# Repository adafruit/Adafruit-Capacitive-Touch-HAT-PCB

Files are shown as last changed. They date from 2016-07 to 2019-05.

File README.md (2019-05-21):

## Adafruit Capacitive Touch HAT PCB
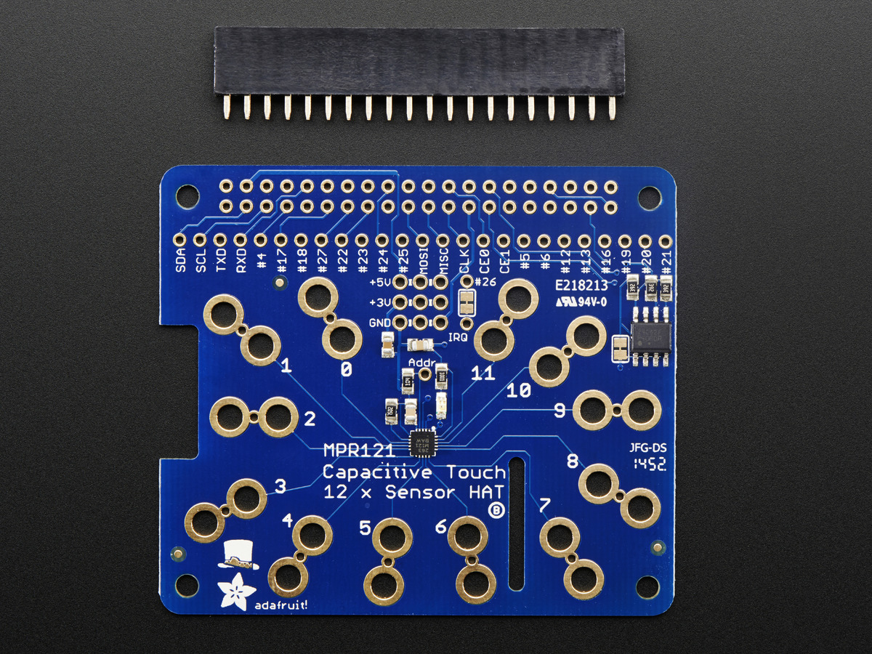
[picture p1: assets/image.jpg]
<a href="http://www.adafruit.com/products/2340"><br/>
Click here to purchase one from the Adafruit shop</a>

This touch-able add on HAT for Raspberry Pi will inspire your next interactive project with 12 capacitive touch sensors. Capacitive touch sensing works by detecting when a person (or animal) has touched one of the sensor electrodes. Capacitive touch sensing used for stuff like touch-reactive tablets and phones, as well as control panels for appliances, which is where you may have used it before. This HAT allows you to create electronics that can react to human touch, with up to 12 individual sensors.

The HAT has 12 'figure 8' holes in it that can be gripped onto with alligator clip cables. Attach one side of the clip to the HAT and the other side to something electrically conductive (like metal) or full of water (like vegetables or fruit!) Then start up our handy Python library code to detect when the object is touched. That's pretty much it, very easy! For advanced users, you can also solder to a pad to make a slimmer & more permanent connection.

PCB files for the Adafruit Capacitive Touch HAT. The format is EagleCAD schematic and board layout
- https://www.adafruit.com/products/2340

### License

Adafruit invests time and resources providing this open source design, please support Adafruit and open-source hardware by purchasing products from [Adafruit](https://www.adafruit.com)!

All text above must be included in any redistribution

Designed by Limor Fried/Ladyada for Adafruit Industries.
Creative Commons Attribution/Share-Alike, all text above must be included in any redistribution. 
See license.txt for additional information.

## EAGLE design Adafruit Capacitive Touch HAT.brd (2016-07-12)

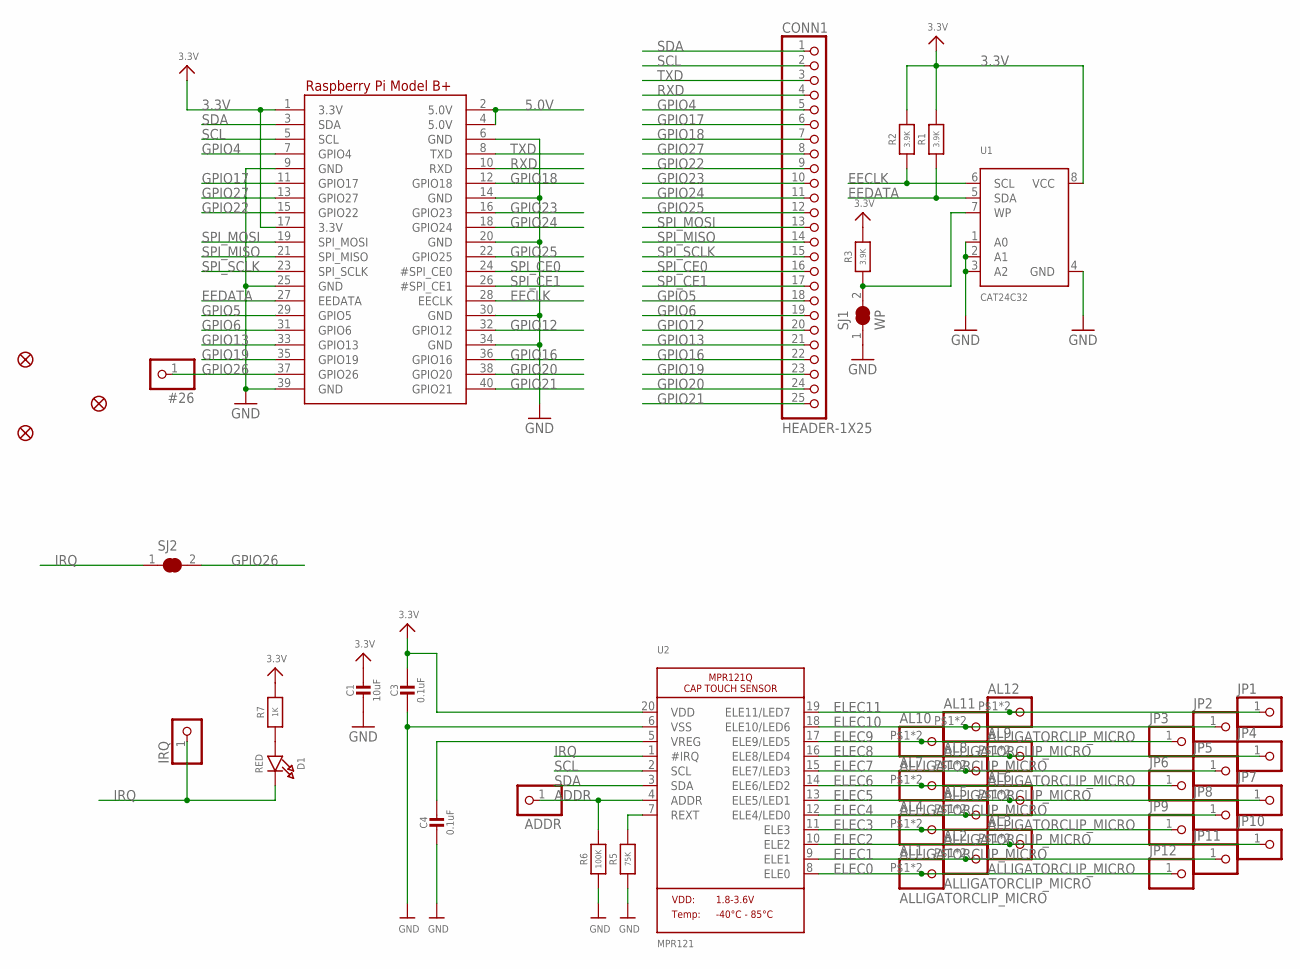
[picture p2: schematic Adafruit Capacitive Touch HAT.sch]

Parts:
#26: HEADER-1X1ROUND; 1X01_ROUND
ADDR: HEADER-1X1ROUND; 1X01_ROUND
AL1, AL2, AL3, AL4, AL5, AL6, AL7, AL8, AL9, AL10, AL11, AL12: ALLIGATORCLIP_MICRO; ALLIGATORCLIP
C1: 10uF; 0805-NO
C3, C4: 0.1uF; 0805-NO
CONN1: HEADER-1X25; 1X25_ROUND_70MIL
D1: RED; CHIPLED_0805_NOOUTLINE
FID1, FID2, FID3: FIDUCIAL""; FIDUCIAL_1MM
IRQ: HEADER-1X1ROUND; 1X01_ROUND
JP1, JP2, JP3, JP4, JP5, JP6, JP7, JP8, JP9, JP10, JP11, JP12: HEADER-1X1ROUND; 1X01_ROUND
R1, R2, R3: 3.9K; 0805-NO
R5: 75K; 0805-NO
R6: 100K; 0805-NO
R7: 1K; 0805-NO
RPI1: RASPBERRYPI_BPLUS_HATSLOTS; PI_HAT_SLOTS
SJ1: WP; SOLDERJUMPER_CLOSEDWIRE
SJ2: SOLDERJUMPER_CLOSED; SOLDERJUMPER_CLOSEDWIRE
U1: CAT24C32; SOIC8_150MIL
U2: MPR121; QFN20_3MM_NOTHERMAL

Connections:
3.3V: C1.1, C3.1, R1.2, R2.2, R3.2, R7.2, RPI1.1 (3.3V), RPI1.17 (3.3V), U1.8 (VCC), U2.20 (VDD)
5.0V: RPI1.2 (5.0V), RPI1.4 (5.0V)
ADDR: ADDR.1, R6.2, U2.4 (ADDR)
EECLK: R2.1, RPI1.28 (EECLK), U1.6 (SCL)
EEDATA: R1.1, RPI1.27 (EEDATA), U1.5 (SDA)
ELEC0: AL1.P$1, AL1.P$2, JP12.1, U2.8 (ELE0)
ELEC1: AL2.P$1, AL2.P$2, JP11.1, U2.9 (ELE1)
ELEC2: AL3.P$1, AL3.P$2, JP10.1, U2.10 (ELE2)
ELEC3: AL4.P$1, AL4.P$2, JP9.1, U2.11 (ELE3)
ELEC4: AL5.P$1, AL5.P$2, JP8.1, U2.12 (ELE4/LED0)
ELEC5: AL6.P$1, AL6.P$2, JP7.1, U2.13 (ELE5/LED1)
ELEC6: AL7.P$1, AL7.P$2, JP6.1, U2.14 (ELE6/LED2)
ELEC7: AL8.P$1, AL8.P$2, JP5.1, U2.15 (ELE7/LED3)
ELEC8: AL9.P$1, AL9.P$2, JP4.1, U2.16 (ELE8/LED4)
ELEC9: AL10.P$1, AL10.P$2, JP3.1, U2.17 (ELE9/LED5)
ELEC10: AL11.P$1, AL11.P$2, JP2.1, U2.18 (ELE10/LED6)
ELEC11: AL12.P$1, AL12.P$2, JP1.1, U2.19 (ELE11/LED7)
GND: C1.2, C3.2, C4.2, R5.1, R6.1, RPI1.6 (GND), RPI1.9 (GND), RPI1.14 (GND), RPI1.20 (GND), RPI1.25 (GND), RPI1.30 (GND), RPI1.34 (GND), RPI1.39 (GND), SJ1.1, U1.1 (A0), U1.2 (A1), U1.3 (A2), U1.4 (GND), U2.6 (VSS)
GPIO4: CONN1.5, RPI1.7 (GPIO4)
GPIO5: CONN1.18, RPI1.29 (GPIO5)
GPIO6: CONN1.19, RPI1.31 (GPIO6)
GPIO12: CONN1.20, RPI1.32 (GPIO12)
GPIO13: CONN1.21, RPI1.33 (GPIO13)
GPIO16: CONN1.22, RPI1.36 (GPIO16)
GPIO17: CONN1.6, RPI1.11 (GPIO17)
GPIO18: CONN1.7, RPI1.12 (GPIO18)
GPIO19: CONN1.23, RPI1.35 (GPIO19)
GPIO20: CONN1.24, RPI1.38 (GPIO20)
GPIO21: CONN1.25, RPI1.40 (GPIO21)
GPIO22: CONN1.9, RPI1.15 (GPIO22)
GPIO23: CONN1.10, RPI1.16 (GPIO23)
GPIO24: CONN1.11, RPI1.18 (GPIO24)
GPIO25: CONN1.12, RPI1.22 (GPIO25)
GPIO26: #26.1, RPI1.37 (GPIO26), SJ2.2
GPIO27: CONN1.8, RPI1.13 (GPIO27)
IRQ: D1.C, IRQ.1, SJ2.1, U2.1 (#IRQ)
unnamed: R3.1, SJ1.2, U1.7 (WP)
unnamed: C4.1, U2.5 (VREG)
unnamed: R5.2, U2.7 (REXT)
unnamed: D1.A, R7.1
RXD: CONN1.4, RPI1.10 (RXD)
SCL: CONN1.2, RPI1.5 (SCL), U2.2 (SCL)
SDA: CONN1.1, RPI1.3 (SDA), U2.3 (SDA)
SPI_CE0: CONN1.16, RPI1.24 (#SPI_CE0)
SPI_CE1: CONN1.17, RPI1.26 (#SPI_CE1)
SPI_MISO: CONN1.14, RPI1.21 (SPI_MISO)
SPI_MOSI: CONN1.13, RPI1.19 (SPI_MOSI)
SPI_SCLK: CONN1.15, RPI1.23 (SPI_SCLK)
TXD: CONN1.3, RPI1.8 (TXD)

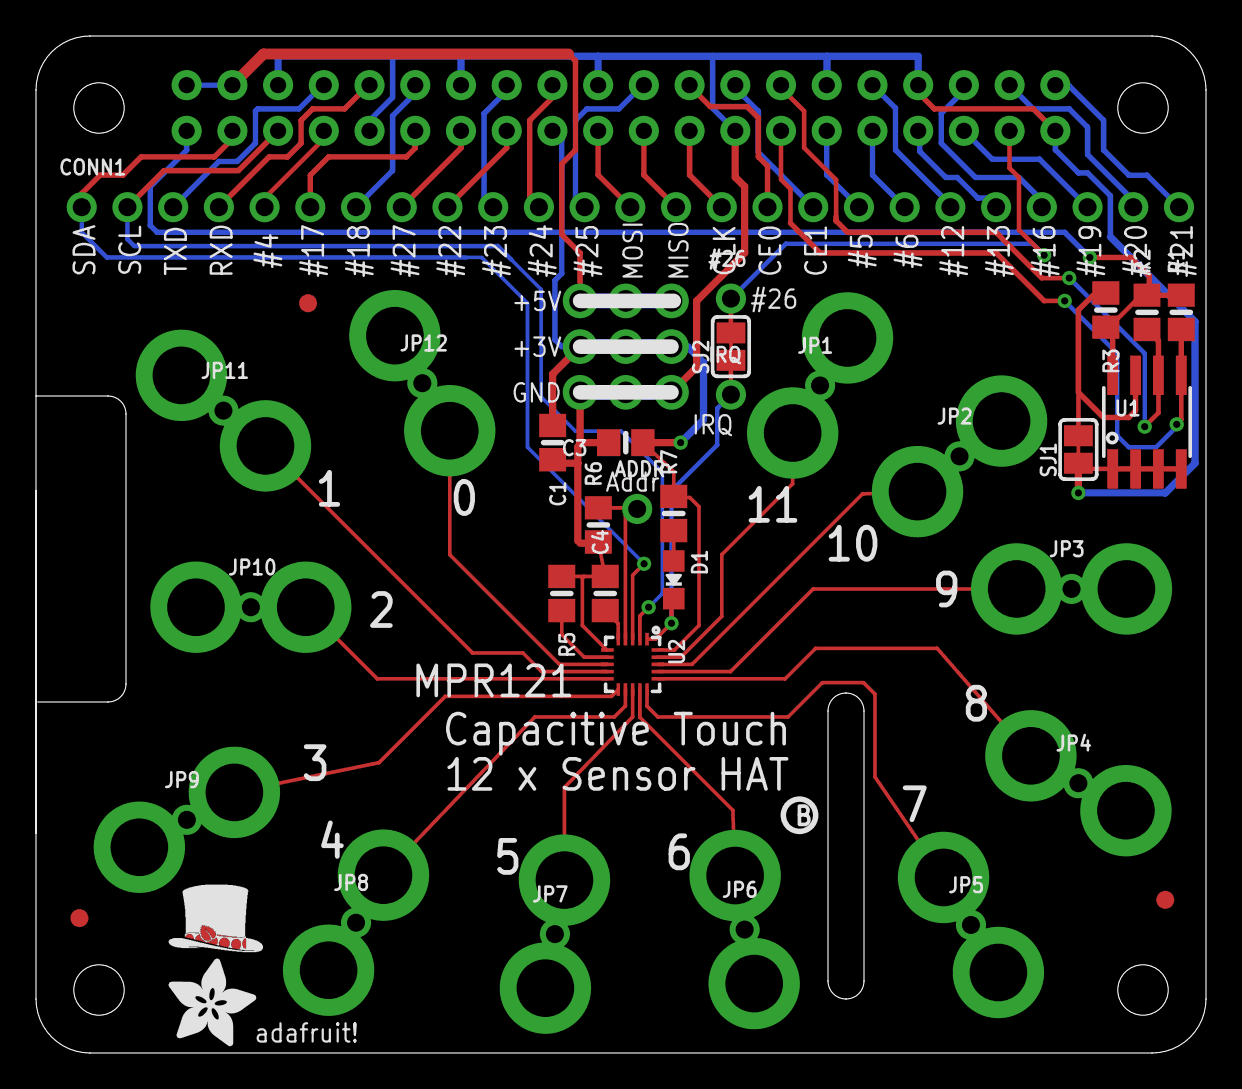
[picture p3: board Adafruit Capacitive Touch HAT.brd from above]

Board: 2 copper layers, 65.0 x 56.5 mm, 49 parts (0 on the bottom side), 49 nets.

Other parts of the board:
U$5: PIHATLOGO
U$6: PCBFEAT-REV-040
U$51: ADAFRUIT_5MM

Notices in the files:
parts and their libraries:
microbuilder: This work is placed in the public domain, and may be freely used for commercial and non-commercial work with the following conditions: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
